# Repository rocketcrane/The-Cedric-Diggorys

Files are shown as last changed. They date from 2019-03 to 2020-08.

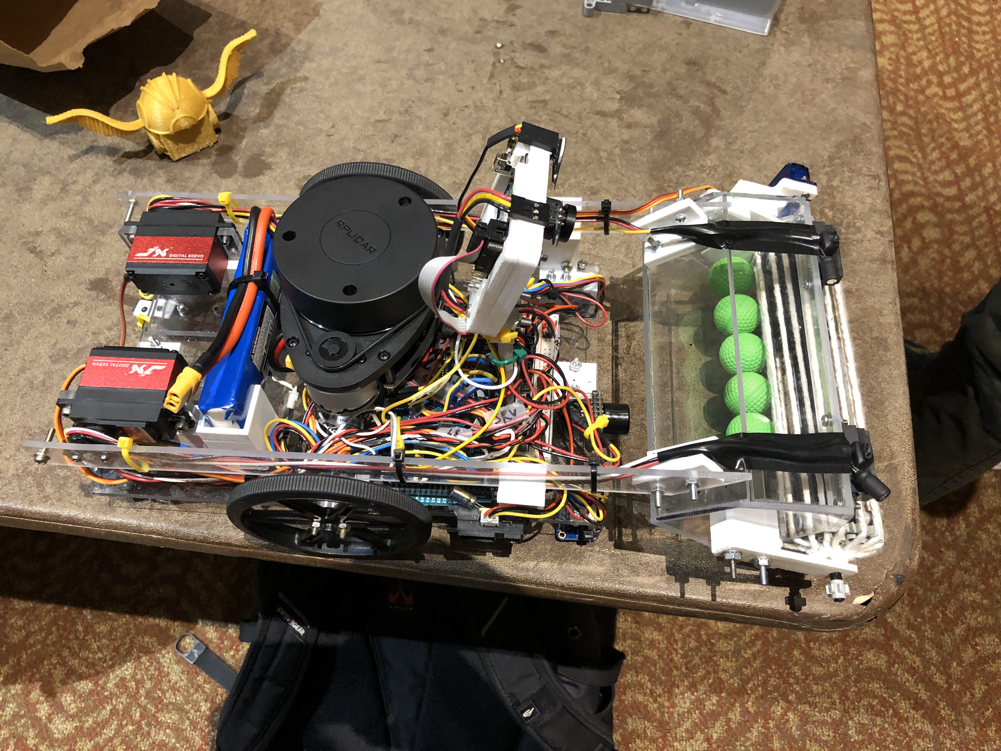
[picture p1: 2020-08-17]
cedric-pictures/IMG_1929.jpeg

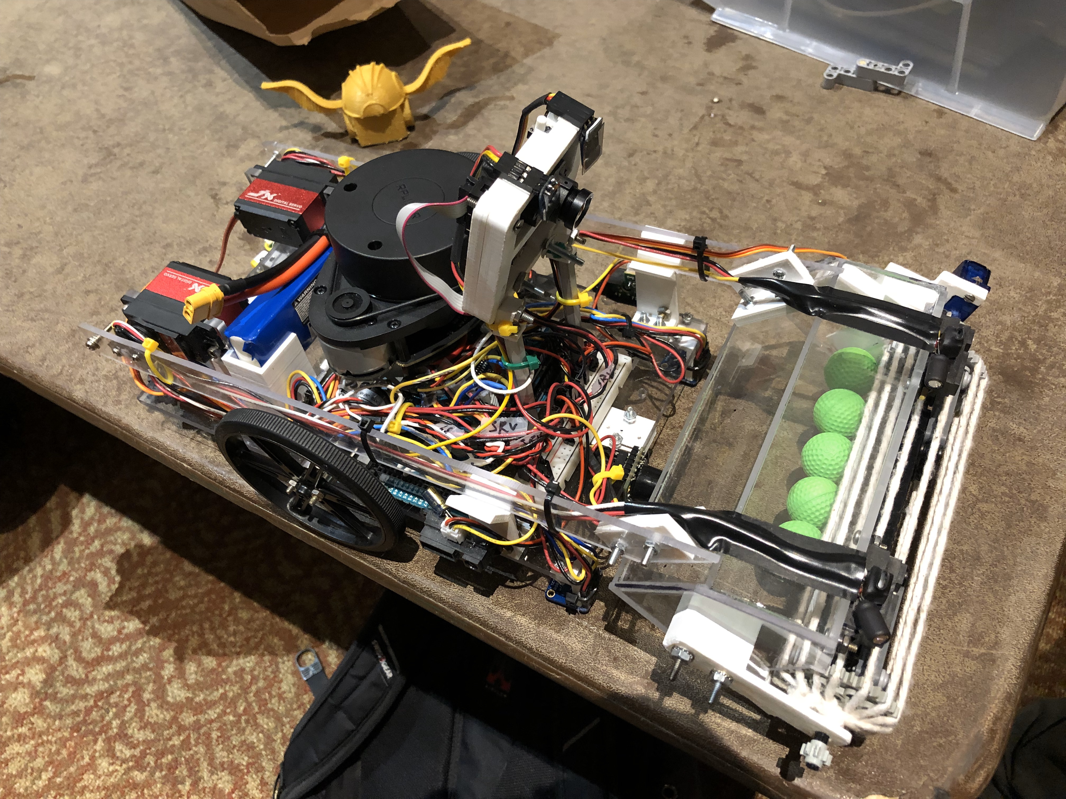
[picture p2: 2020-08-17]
cedric-pictures/IMG_1928.jpeg

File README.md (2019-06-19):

# We are the Triwizard Tournament Co-champions!
Update: We are the quidditch tournament champions!

Congratulations Cedric.

Best of luck to Ben at his new job,

Tomas with his Computer Science Major,

and Lingxiu with his Cognitive Science one.

-------------------------The Cedric Diggorys signing out.-------------------------

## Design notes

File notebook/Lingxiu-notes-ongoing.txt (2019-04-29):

# Notes for Lingxiu Zhang

First 3 weeks:
  Organized meetings, took (most of our) notes, brainstormed, found different types of sensors, hooked up sensors to Arduino
  forked TEAM-YELLOW, created the-Cedric-Diggorys

Feb 18, 2019
  Soldered pins to sonar sensor, hooked sensors and motors up to arduino, soldered wires to motor. Tested different types of motors. Discussed with other people in our group about the drivetrain, chassis, ball-pick-up and ball-shooting mechanisms. Asked Carl (with other members) about our design ideas, was told to meet him tomorrow. Did research on wiring/using Arduino motor shield.
  Also researched about mecanum/omni wheels and the possibility of using a roomba extractor brush as a part of our ball-pick-up mechanism. Turns out omni wheels can be arranged in an x-drive or a triangle-drive allowing for full mobility, including strafing to both sides. Put this in our (google doc) team notes.

Feb 22, 2019
  Discussed finishing milestones, robot's physical design etc. Worked with Ben to build a LEGO prototype robot capable of moving forward. Searched online for wheels that we could use for our robot and settled on two possible wheels types. Took notes. Researched LIDAR and a real SLAM LIDAR that might help our robot a lot. Discussed if it would be worth it to buy such a LIDAR, and we came to the conslusion that if we still had most of our budget by spring break, then we would get it. Talked about using rubber bands in our cylinder, and decided to get rubber bands and prototype our design next time.
  
Feb 24 - Apr 4, 2019
  Built an iteration of the chassis design on foam core board, did all the electronics work, designed and prototyped a quaffle-collection mechanism, built two prototypes of the mechanism (one from Legos, one from foam core board). Researched and bought a LIDAR unit during spring break. Worked with Carl to start build a proper chassis from Arcrylic.
  
Apr 4 - Apr 21
  Designed and built the third (and definitely last) iteration of the chassis + all hardware. I designed + prototyped all arcylic parts, which were built by Cart at the machine shop. All 3D-printed parts, except the camera mount, were designed and printed by myself. I  wired and installed all the electronics. I put together nearly all robot hardware, which is currently (at 4/21) 95% finished, and I plan to move on to support Ben with the software effort. What's left of the hardware work is installing the light sensors with polarized filters, and installing a few more IR sensors.
   I have been in the lab at least two extra days each week for the last three weeks working primarily on the robot hardware. Setting up and debugging the 3D printer took about three days, and I finally realized that the filament was the main culprit in causing all prints to warp badly. So I replaced the filament, and the printer didn't give me any issues after that. The next few days were spent coordinating with Carl to build the plow and servo mounts, printing and installing multiple parts including caster wheel mounts and ultrasonic sensor mounts, and wiring sensors. Then I mounted the Pixycam by modifying Tomas's 3D printed mount and mounting it to standoffs on the chassis. Then more parts were mounted, blah blah blah, dramatic music and montage of power tools and 3D printing, and the hardware side of things is almost completely finished.

Apr 21 - Apr 29
  Finished robot hardware. Wired and installed all IR sensors, a sonar sensor, and two light sensors with polarized light detection. Installed a replacement servo for the low-torque servo. Built a battery voltage monitor for the Arduino. Tweaked and optimized wiring on the robot. Designed and 3d printed battery mount brackets.
  Starting to help Ben with software.

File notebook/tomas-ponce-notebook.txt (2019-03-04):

Week 3: 2/11/19-2/17/19

This week I focused on looking up some research on the senors we have avaliable to us. In particular was researching
the limitations that the sensors each had.
	-Brighter surfaces are easier for the infrared to detect since it can't detect dark surfaces very well
	-Ultrasonics aren't as good as infrared at defining edges
The rest of the team feel very condient in being able to use the senors.
I was also researching potential drive trains for the robot. So far I really like the use of mecanum for the robot.
Beginning to model our ideas. So far have just drawn them on paper. 
Hope to have some parts of the robot made next week.

Week 4: 2/18/19-2/24/19

This week I was focused only on modeling the parts of our robot. We have made the decision to design/model the final 
parts of our robot as we construct our prototype. The parts I managed to complete were the plow and the two seperate 
models that will be used to hold our camera. The plow will go in front of our robot as it drives fowards and picks up 
balls along the way. The two parts that will hold the camera are to be printed seperately and then assemble together 
for the camera. The actual body and the base that will hold the wheels are to be made next. 

Week 5: 2/25/19-3/4/19 

This week I finally managed to get one of the parts printed. After a while of trying to get the fie to work with
one of the printers, the front part of the camera holder was made. The print was not ideal. One lesson learned from
the print was to increase the scale of the part. Due to several factors concerning the printer and how the plastic
dried, the print was just a little too tight to fit neatly around the camera. The holes that went around the part 
also did not come out as desired. The pegs that were originally a part of the design also were a problem. They were 
changed to holes so a bolt and nut could hold the two halves together. The back half of the camera was also changed 
due to this revelation. Work on the chasis model and other features are underway.

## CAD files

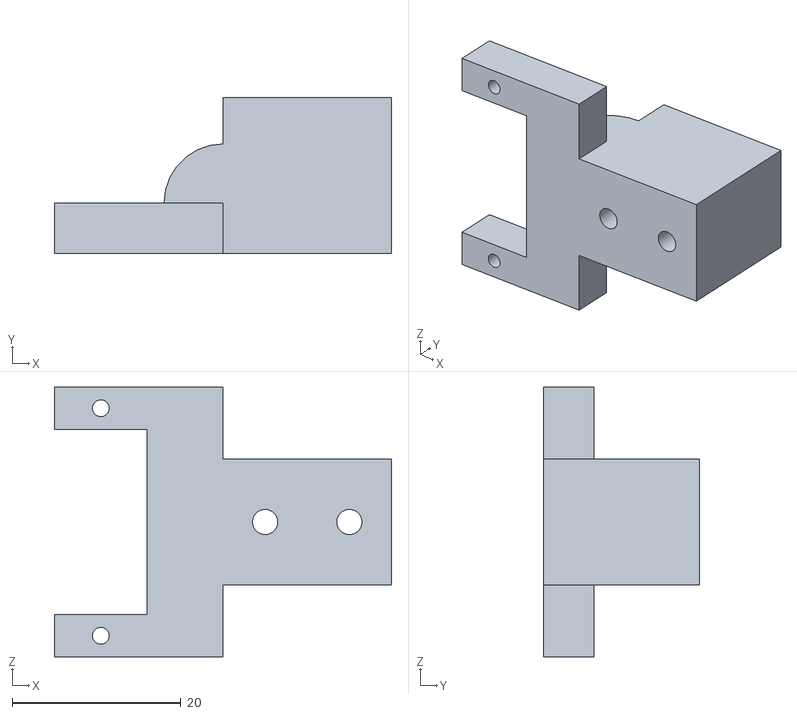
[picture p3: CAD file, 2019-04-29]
notebook/Lingxiu-3d-models/CRServo-Mt 1.1.stl
40.0 x 18.5 x 32.0

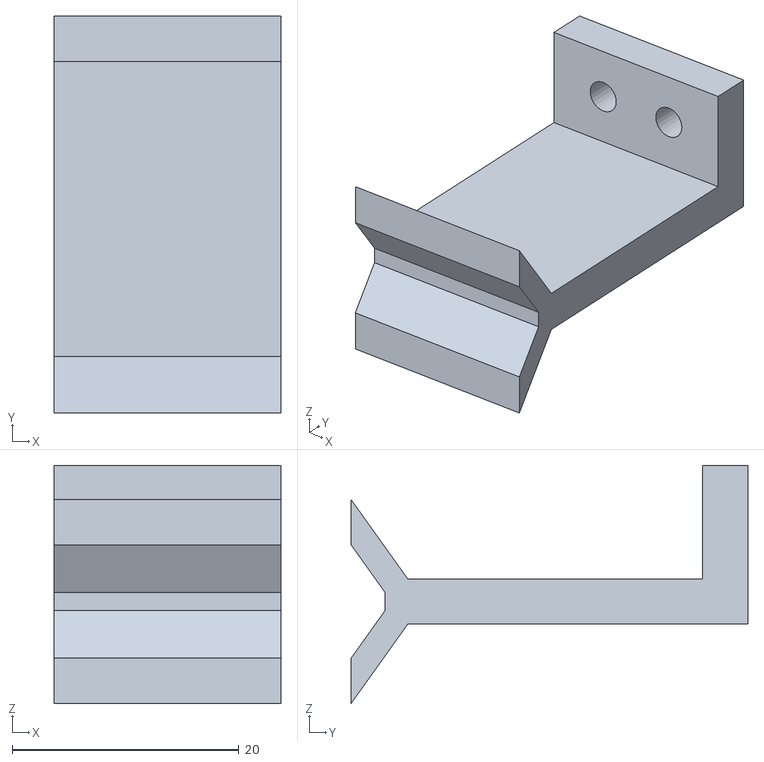
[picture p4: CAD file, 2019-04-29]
notebook/Lingxiu-3d-models/WD6_Stop-Arm 1.1.stl
20.0 x 35.0 x 21.0

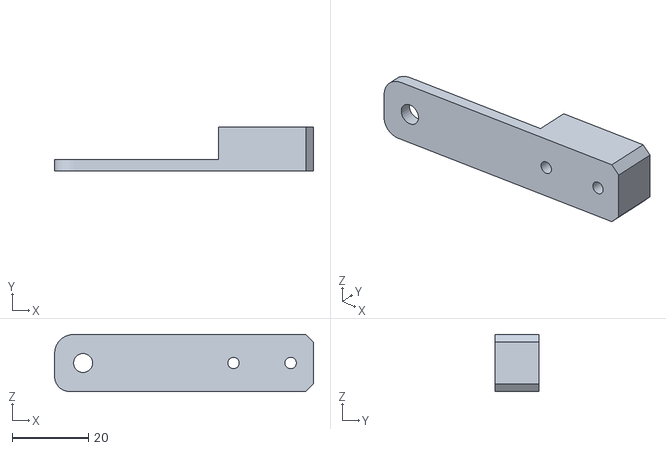
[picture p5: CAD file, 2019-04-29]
notebook/Lingxiu-3d-models/Cylinder-Mt 1.1.stl
68.0 x 11.6 x 15.0

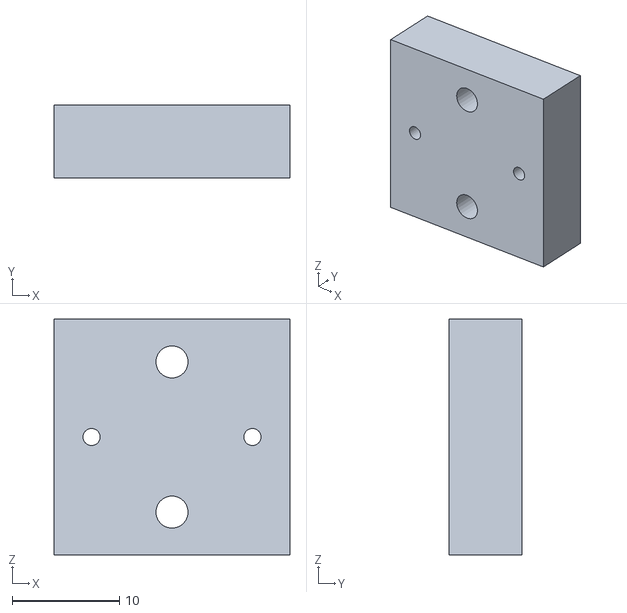
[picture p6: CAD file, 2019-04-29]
notebook/Lingxiu-3d-models/Caster-Mt 1.0.stl
22.0 x 6.80 x 22.0

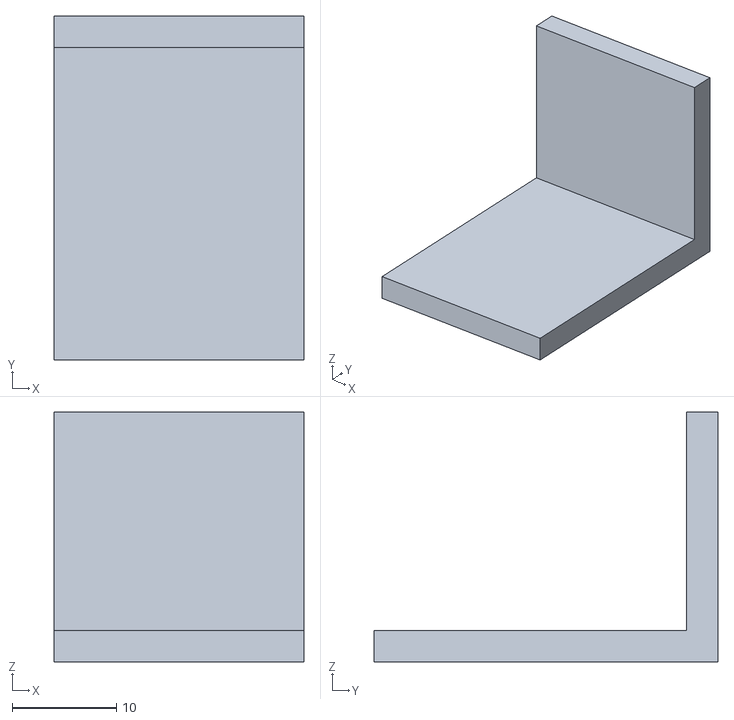
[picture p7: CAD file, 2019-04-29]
notebook/Lingxiu-3d-models/bat-mt 1.0.stl
24.0 x 33.0 x 24.0

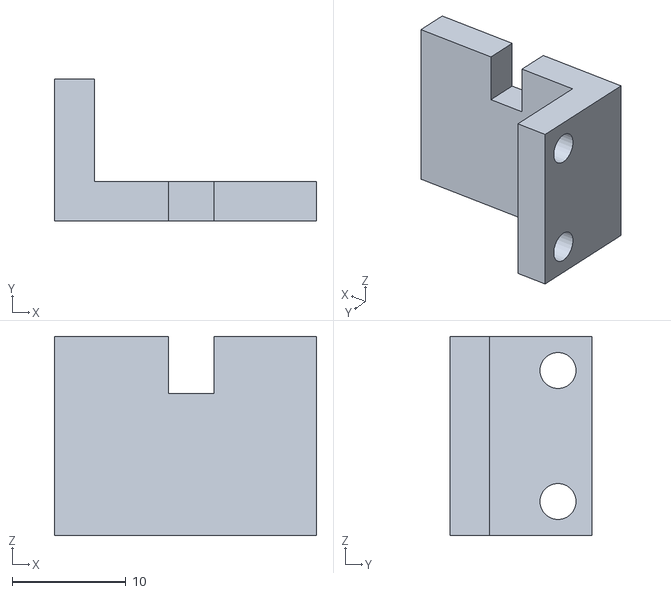
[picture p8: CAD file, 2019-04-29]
notebook/Lingxiu-3d-models/Ultson-Mt 1.0.stl
23.0 x 12.5 x 17.5

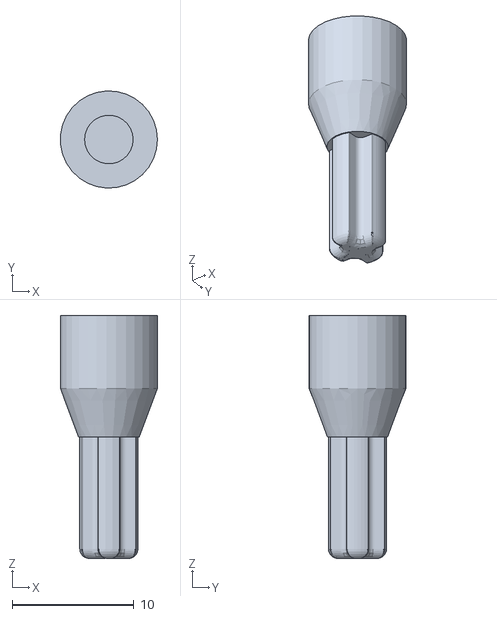
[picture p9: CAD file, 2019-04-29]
notebook/Lingxiu-3d-models/Servo-Lego Axle v2.0.stl
7.98 x 7.99 x 20.0

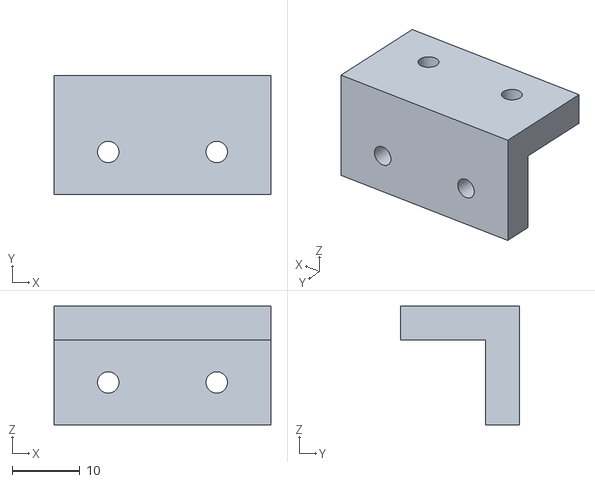
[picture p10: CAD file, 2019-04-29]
notebook/Lingxiu-3d-models/l-bracket 1.0.stl
32.0 x 17.5 x 17.5

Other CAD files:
notebook/Lingxiu-3d-models/chassis.dwg
Robot 3-D Models/90mm Wheel.ipt
Robot 3-D Models/BS #1.ipt
Robot 3-D Models/BS #2.ipt
Robot 3-D Models/BS #3.ipt
Robot 3-D Models/JX PDI 6221MG Servo.ipt
Robot 3-D Models/Mounting Hub.ipt
Robot 3-D Models/Part2.ipt
Robot 3-D Models/Plow.ipt
Robot 3-D Models/arduino mega 2560.ipt
Robot 3-D Models/arm.ipt
Robot 3-D Models/back-cam.ipt
Robot 3-D Models/ball.ipt
Robot 3-D Models/base plate.ipt
Robot 3-D Models/battery-holder-two.ipt
Robot 3-D Models/battery-holder.ipt
Robot 3-D Models/battery.ipt
Robot 3-D Models/breadboard.ipt
Robot 3-D Models/camera-brackets-angle.ipt
Robot 3-D Models/fixed-back-cam.ipt
Robot 3-D Models/fixed-front-cam.ipt
Robot 3-D Models/front-cam.ipt
Robot 3-D Models/jam-protector-two.ipt
Robot 3-D Models/jam-protector.ipt
Robot 3-D Models/motor-rail.ipt
Robot 3-D Models/motor.ipt
Robot 3-D Models/plowV2.ipt
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

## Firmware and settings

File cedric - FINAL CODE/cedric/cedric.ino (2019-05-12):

#include <Adafruit_TCS34725softi2c.h>

#include <Arduino.h>
#include <RPLidar.h>
#include <Wire.h>
#include <Servo.h>
#include <SPI.h>
#include <Pixy.h>
#include <Adafruit_TCS34725.h>
#include "sensors.h"
#include "motors.h"
#include "servos.h"
#include "variables.h"

int const STARTINGSIDE = BLUE_SIDE; //CHOOSE STARTING SIDE

void setup() {
  //WAIT FOR X SECONDS
  delay(0 * 1000L);

  //------------------------PIN MODES------------------------
  pinMode(LEFT_FRONT_IR_PIN, INPUT);
  pinMode(RIGHT_FRONT_IR_PIN, INPUT);
  pinMode(LEFT_REAR_IR_PIN, INPUT);
  pinMode(RIGHT_REAR_IR_PIN, INPUT);
  pinMode(LEFT_IR_PIN, INPUT);
  pinMode(RIGHT_IR_PIN, INPUT);
  pinMode(SONAR_PIN, INPUT);
  pinMode(LEFT_LIGHT_PIN, INPUT);
  pinMode(RIGHT_LIGHT_PIN, INPUT);
  pinMode(VOLT_PIN, INPUT);
  pinMode(A_DIRECTION_PIN, OUTPUT);
  pinMode(B_DIRECTION_PIN, OUTPUT);
  pinMode(A_BRAKE_PIN, OUTPUT);
  pinMode(B_BRAKE_PIN, OUTPUT);

  //------------------------START ROBOT------------------------
  Serial.begin(9600);
  Serial.println("-------------------CEDRIC DIGGORY-------------------");
  Serial.println("----------TRIWIZARD TOURNAMENT CO-CHAMPION----------");
  Serial.print("booting");
  for (int i = 0; i < 20; i++) {
    delay(200);
    Serial.print(".");
  }
  Serial.println();

  //START RGB SENSORS AND PIXY
  leftRGB.begin();
  rightRGB.begin();
  rearRGB.begin();
  pixy.init();

  //RESET VARIABLES
  quaffleDetectedRight = 0;
  quaffleDetectedLeft = 0;
  leakyIntegrator = 40;
  location = 0;
  currSide = 0;
  state = COLLECTING;

  //SET INITIAL STATE
  if (STARTINGSIDE == BLUE_SIDE) {
    Serial.println("BLUE side home");
    currSide = BLUE_SIDE;
    location = BLUE_SIDE;
    homeSide = BLUE_SIDE;
    goalSide = RED_SIDE;
    scoringWallSidePin = RIGHT_IR_PIN;
    scoringTurnDirection = LEFT;
  }
  if (STARTINGSIDE == RED_SIDE) {
    Serial.println("RED side home");
    currSide = RED_SIDE;
    location = RED_SIDE;
    homeSide = RED_SIDE;
    goalSide = BLUE_SIDE;
    scoringWallSidePin = RIGHT_IR_PIN;
    scoringTurnDirection = LEFT;
  }

  //START MOVING
  if (state == COLLECTING) forward(FORWARD_SPEED);
  rollIn();
}

void loop() {
  //------------------------MAIN ROBOT CODE------------------------
  while (millis() < END_TIME) {

    //UPDATE VARIABLES AND GRAB SENSOR DATA
    unsigned long currentMillis = millis();
    //grab pixy blocks
    uint16_t blocks;
    blocks = pixy.getBlocks();
    //generic loop counter for Pixy
    int j;
    quaffleSeenThisLoop = 0;
    //grab RGB sensor data & convert to HSV
    leftRGB.getRawData(&red, &green, &blue, &clear);
    RGBtoHSV(red, green, blue, &leftHue, &s, &v);
    rightRGB.getRawData(&red, &green, &blue, &clear);
    RGBtoHSV(red, green, blue, &rightHue, &s, &v);
    rearRGB.getRawData(&red, &green, &blue, &clear);
    RGBtoHSV(red, green, blue, &rearHue, &s, &v);
    //CHECK BATTERY LEVEL
    if (getVoltage() < LOW_BATTERY_LEVEL) {
      Serial.println("I'LL BE BACK");
    }

    //SWITCH TO SCORING MODE IF TIME HAS PAST
    if (currentMillis >= scoreTime && isRed(rightHue) && state == COLLECTING) {
      lastColorSeen = RED_TAPE;
      brake();
      state = FOLLOW_LINE;
      raiseArmHigher();
      Serial.println("found line");
    }

    //------------------------COLLECTING STATE------------------------
    if (state == COLLECTING) {

      //UPDATE LEAKY INTEGRATOR
      if (leakyIntegrator > DECAY && currentMillis - previousMillis >= INTERVAL) {
        leakyIntegrator -= DECAY;
        previousMillis = millis(); //updates time
        //prints integrator values
        //Serial.print("Integrator: ");
        //Serial.println(leakyIntegrator);
      }

      //IF INTEGRATOR IS HIGH, REVERSE A BIT THEN TURN UNTIL YOU SEE OPEN SPACE
      if (leakyIntegrator > SENSITIVITY) {
        //variables to tune behavior
        int turnLoopAmount = 3 * 100; //roughly time in seconds
        int turnRandomTime = 600;
        int backTime = 500;
        //sets leaky integrator back to RESET value
        leakyIntegrator = RESET;
        //prints that integrator is high
        Serial.println("Integrator HIGH");

        //reverses a bit
        reverseTime(backTime);

        //turns the opposite direction to current motor state
        if (motorState == SPINLEFT || motorState == TURNLEFT) {
          right(TURNING_SPEED);
          Serial.println("Turning RIGHT (high)");
          for (int i = 0; i < turnLoopAmount; i++ && getIRVal(LEFT_FRONT_IR_PIN) < 40 && getIRVal(RIGHT_FRONT_IR_PIN) < 40) {
            delay(10);
          }
          forward(FORWARD_SPEED);
        }
        else if (motorState == SPINRIGHT || motorState == TURNRIGHT) {
          left(TURNING_SPEED);
          Serial.println("Turning LEFT (high)");
          for (int i = 0; i < turnLoopAmount; i++ && getIRVal(LEFT_FRONT_IR_PIN) < 40 && getIRVal(RIGHT_FRONT_IR_PIN) < 40) {
            delay(10);
          }
          forward(FORWARD_SPEED);
        }
        //or do a random turn if robot is not currently turning
        else {
          Serial.println("Turning RANDOM (high)");
          randTurn(turnRandomTime);
        }
      }

      //IF INTEGRATOR DECAYS TO ZERO, BACK UP AND THEN TURN IN OPPOSITE DIRECTION TO CURRENT TURNING DIRECTION
      if (leakyIntegrator <= DECAY) {
        //variables to tune behavior
        int turnOppositeTime = 400;
        int turnRandomTime = 600;
        int backTime = 500;
        //reset leaky integrator to RESET
        leakyIntegrator = RESET;
        //prints that integrator is LOW
        Serial.println("Integrator LOW");

        //reverses a bit
        reverseTime(backTime);

        //turns opposite direction to current motor state
        if (motorState == SPINLEFT || motorState == TURNLEFT) {
          Serial.println("Turning RIGHT (low)");
          spinRightTime(turnOppositeTime);
        }
        else if (motorState == SPINRIGHT || motorState == TURNRIGHT) {
          Serial.println("Turning LEFT (low)");
          spinLeftTime(turnOppositeTime);
        }
        //or do a random turn if robot is not currently turning
        else {
          Serial.println("Turning RANDOM (low)");
          randTurn(turnRandomTime);
        }
      }

      //IF LEFT RGB SENSOR OR FRONT LEFT IR SENSOR IS TRIGGERED, BACK UP A BIT AND SPIN RIGHT
      if (isYellow(leftHue) || getIRVal(LEFT_FRONT_IR_PIN) < 6) {
        //variables to tune behavior
        unsigned long backTime = 200;
        unsigned long turnTime = 400;
        //integrate leaky integrator
        leakyIntegrator += INTEGRATE;
        Serial.println("LRGB/FLIR turning RIGHT");

        reverseTime(backTime);
        spinRightTime(turnTime);
      }

      //IF RIGHT RGB SENSOR OR FRONT RIGHT IR SENSOR IS TRIGGERED, BACK UP A BIT AND SPIN LEFT
      if (isYellow(rightHue) || getIRVal(RIGHT_FRONT_IR_PIN) < 6) {
        //variables to tune behavior
        unsigned long backTime = 200;
        unsigned long turnTime = 400;
        //integrate leaky integrator
        leakyIntegrator += INTEGRATE;
        Serial.println("RRGB/FRIR turning LEFT");

        reverseTime(backTime);
        spinLeftTime(turnTime);
      }

      //IF LEFT IR SENSOR OR RIGHT REAR IR SENSOR IS TRIGGERED, TURN RIGHT
      if (getIRVal(LEFT_IR_PIN) < 5 || getIRVal(RIGHT_REAR_IR_PIN) < 5) {
        //variables to tune behavior
        unsigned long turnTime = 500;
        //integrate leaky integrator
        leakyIntegrator += INTEGRATE;
        Serial.println("LIR/RRIR turning RIGHT");

        turnLeftTime(turnTime);
      }

      //IF RIGHT IR SENSOR OR LEFT REAR IR SENSOR IS TRIGGERED, TURN LEFT
      if (getIRVal(RIGHT_IR_PIN) < 5 || getIRVal(LEFT_REAR_IR_PIN) < 5) {
        //variables to tune behavior
        unsigned long turnTime = 500;
        //integrate leaky integrator
        leakyIntegrator += INTEGRATE;
        Serial.println("RIR/RLIR turning RIGHT");

        turnRightTime(turnTime);
      }

      //IF PIXYCAM SEES A GREEN BALL, UPDATE VARIABLES AND TRY TO FOLLOW
      if (blocks) {

        //for each block, check signature
        for (j = 0; j < blocks; j++) {
          if (pixy.blocks[j].signature == GREEN_SIG) {
            //update variables
            loopsSinceQuaffleSeen = 0;
            quaffleSeenThisLoop = 1;
            quaffleDetected = 1;
            //get quaffle X and Y
            quaffleX = pixy.blocks[j].x;
            quaffleY = pixy.blocks[j].y;
            Serial.println("quaffle DETECTED");
          }
          if (pixy.blocks[j].signature == YELLOW_SIG && (pixy.blocks[j].height * pixy.blocks[j].width) > 300) {
            //update variables
            loopsSinceGoalSeen = 0;
            goalSeenThisLoop = 1;
            goalDetected = 1;
            Serial.println("goal DETECTED");
          }
        }

        //TRY TO FOLLOW A GREEN BALL IF IT EXISTS
        if (quaffleSeenThisLoop) {
          //if quaffle is within buffer begin turning
          if (quaffleX > (155 + ALLOWABLE_BUF) && quaffleDetectedRight == 0) {
            forwardRight(TURNING_SPEED);
            Serial.println("quaffle detected to the RIGHT");
            quaffleDetectedRight = 1;
          }
          if (quaffleX < (155 - ALLOWABLE_BUF) && quaffleDetectedLeft == 0 && !quaffleDetectedRight) {
            forwardLeft(TURNING_SPEED);
            Serial.println("quaffle detected to the LEFT");
            quaffleDetectedLeft = 1;
          }
          //if quaffle is centered then go forward
          if (quaffleX < 155 + TARGET_BUF && quaffleDetectedRight == 1 ) {
            forward(FORWARD_SPEED);
            quaffleDetectedRight = 0;
            Serial.println("quaffle CENTERED");
          }
          if (quaffleX > 155 - TARGET_BUF && quaffleDetectedLeft == 1) {
            forward(FORWARD_SPEED);
            quaffleDetectedLeft = 0;
            Serial.println("quaffle CENTERED");
          }
        }
      }

      //if no quaffle has been seen this loop, increment counter
      if (!quaffleSeenThisLoop) {
        loopsSinceQuaffleSeen ++;
      }
      //if no goal has been seen this loop, increment counter
      if (!goalSeenThisLoop) {
        loopsSinceGoalSeen ++;
      }

      //if quaffle hasn't been seen in X loops, update variables
      if (loopsSinceQuaffleSeen > 10 && quaffleDetected) {
        Serial.print("quaffle DISAPPEARED");
        //update variables
        quaffleDetectedRight = 0;
        quaffleDetectedLeft = 0;
        quaffleDetected = 0;
      }
      //if goal dissapears
      if (loopsSinceGoalSeen > 10 && goalDetected) {
        Serial.print("goal DISAPPEARED");
        //update variables
        quaffleDetected = 0;
      }
    }

    //------------------------FOLLOW LINE STATE------------------------
    if (state == FOLLOW_LINE) {
      Serial.println("following line");
      Serial.println(rightHue);
      // Serial.println(rightHue);
      if (isRed(rightHue)) {
        Serial.println("red");
        forward(FORWARD_SPEED);
        lastColorSeen = RED_TAPE;
      }
      if (isBlue(rightHue) || lastColorSeen == BLUE_TAPE) {
        Serial.println("blue");
        if (homeSide == BLUE_SIDE) left(TURNING_SPEED);
        else right(TURNING_SPEED);
        lastColorSeen = BLUE_TAPE;
      }
      if (isGray(rightHue) && lastColorSeen == RED_TAPE) {
        Serial.println("gray");
        if (homeSide == BLUE_SIDE) right(TURNING_SPEED);
        else left(TURNING_SPEED);
      }
      if (isYellow(rightHue)) {
        brake();
        Serial.println("Wall detected");
        state = SCORING;
        while (!(isGray(rightHue))) {
          rightRGB.getRawData(&red, &green, &blue, &clear);
          RGBtoHSV(red, green, blue, &rightHue, &s, &v);
          forward(TURNING_SPEED);
        }
        brake();
        while (!(isYellow(rightHue))) {
          Serial.println(rightHue);
          rightRGB.getRawData(&red, &green, &blue, &clear);
          RGBtoHSV(red, green, blue, &rightHue, &s, &v);
          if (scoringTurnDirection == RIGHT) {
            right(TURNING_SPEED);
          }
          else {
            left(TURNING_SPEED);
          }
        }
        brake();
        Serial.println("done no yellow turn");
        while (isYellow(rightHue)) {
          Serial.println(rightHue);
          rightRGB.getRawData(&red, &green, &blue, &clear);
          RGBtoHSV(red, green, blue, &rightHue, &s, &v);
          if (scoringTurnDirection == RIGHT) {
            right(TURNING_SPEED);
          }
          else {
            left(TURNING_SPEED);
          }
        }
        Serial.println("done yellow turn");
        brake();
        while (isYellow(rearHue)) {
          rearRGB.getRawData(&red, &green, &blue, &clear);
          RGBtoHSV(red, green, blue, &rearHue, &s, &v);
          if (scoringTurnDirection == RIGHT) {
            left(TURNING_SPEED);
          }
          else {
            right(TURNING_SPEED);
          }
        }
        lowerArmHigher();
      }
    }

    //------------------------SCORING STATE------------------------
    if (state == SCORING) {
      float wallDist = getIRVal(scoringWallSidePin);
      Serial.println(wallDist);
      if (wallDist < 8 || isYellow(rightHue)) {
        Serial.println("too close to wall");
        if (scoringTurnDirection == RIGHT) right(TURNING_SPEED);
        else left(TURNING_SPEED);
      }

      else {
        if (scoringTurnDirection == RIGHT) forwardLeft(FORWARD_SPEED);
        else forwardRight(FORWARD_SPEED);
      }
      if (getIRVal(LEFT_FRONT_IR_PIN) < 8 && goalDetected) {
        Serial.println("found goal");
        Serial.println(wallDist);
        Serial.println(getIRVal(LEFT_FRONT_IR_PIN));
        Serial.println(getIRVal(RIGHT_FRONT_IR_PIN));
        state = COLLECTING;
        scoreTime = currentMillis + COLLECTING_TIME;
        slowLineUpWall();
        delay(1000);
        raiseArm();
        forward(FORWARD_SPEED);
        delay(400);
        brake();
        rollOut();
        delay(2000);
        reverse(FORWARD_SPEED);
        delay(500);
        brake();
        lowerArm();
        rollIn();
      }
    }
  }


  //STOP ROBOT
  brake();
  stopRoll();
  Serial.println("-------------------MISSION ACCOMPLISHED-------------------");
  Serial.println("----------------CEDRIC DIGGORY SIGNING OFF----------------");
  delay(100);
  exit(0);
}

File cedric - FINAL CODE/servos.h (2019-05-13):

#ifndef SERVOS_H
#define SERVOS_H

#include <Adafruit_TCS34725softi2c.h>

#include <Arduino.h>
#include <RPLidar.h>
#include <Wire.h>
#include <Servo.h>
#include <SPI.h>
#include <Pixy.h>
#include <Adafruit_TCS34725.h>
#include "variables.h"

//------------------------PINS------------------------
//ACTUATORS
int const LEFT_SERVO_PIN = 46;
int const RIGHT_SERVO_PIN = 45;
int const ROLLER_PIN = 10;

//------------------------CONSTANTS------------------------
//ARM CONSTANTS
int const RIGHT_START = 13;
int const LEFT_START = 160 - RIGHT_START;
int const LIFT_ANGLE = 35;
const int HIGHER_LIFT_ANGLE = 55;

//ROLLER STATE CONSTANTS
int const IN = 1;
int const OUT = 2;
int const STOP = 0;

//------------------------DECLARATIONS------------------------
Servo leftServo;
Servo rightServo;
Servo roller;

//------------------------SERVO FUNCTIONS------------------------

// ROLLIN
// ------------------------------------------
// starts roller to collect balls
void rollIn() {
  roller.attach(ROLLER_PIN);
  roller.write(0);
  //update roller state
  rollerState = IN;
}

// ROLLOUT
// ------------------------------------------
// starts roller to score
void rollOut() {
  roller.attach(ROLLER_PIN);
  roller.write(180);
  //update roller state
  rollerState = OUT;
}

// STOPROLL
// ------------------------------------------
// stops and detaches roller servo
void stopRoll() {
  roller.detach();
  //update roller state
  rollerState = STOP;
}

// RAISEARM
// ------------------------------------------
// raises arm
void raiseArm() {
  //attaches both arm servos
  leftServo.attach(LEFT_SERVO_PIN);
  rightServo.attach(RIGHT_SERVO_PIN);
  for (int pos = 0; pos <= LIFT_ANGLE; pos++) { // goes from 0 degrees to 180 degrees
    // in steps of 1 degree
    rightServo.write(RIGHT_START + pos); // tell servo to go to position in variable 'pos'
    leftServo.write(LEFT_START - pos);
    delay(15); // waits 15ms for the servo to reach the position
  }

  if (rollerState == IN) {
    stopRoll();
  }
}

// LOWERARM
// ------------------------------------------
// lowers arm
void lowerArm() {
  for (int pos = LIFT_ANGLE; pos >= 0; pos -= 1) { // goes from 180 degrees to 0 degrees
    rightServo.write(pos + RIGHT_START); // tell servo to go to position in variable 'pos'
    leftServo.write(LEFT_START - pos);
    delay(15); // waits 15ms for the servo to reach the position
  }
  //detaches both arm servos
  leftServo.detach();
  rightServo.detach();

  if (rollerState == STOP) {
    rollIn();
  }
}

// RAISEARMHIGHER
// ------------------------------------------
// raises arm higher to get over wall
void raiseArmHigher() {
  //attaches both arm servos
  leftServo.attach(LEFT_SERVO_PIN);
  rightServo.attach(RIGHT_SERVO_PIN);

  for (int pos = 0; pos <= HIGHER_LIFT_ANGLE; pos++) { // goes from 0 degrees to 180 degrees
    // in steps of 1 degree
    rightServo.write(RIGHT_START + pos); // tell servo to go to position in variable 'pos'
    leftServo.write(LEFT_START - pos);
    delay(15); // waits 15ms for the servo to reach the position
  }

  if (rollerState == IN) {
    stopRoll();
  }
}

// LOWERARMHIGHER
// ------------------------------------------
// lowers arm from higher pos
void lowerArmHigher() {

  for (int pos = HIGHER_LIFT_ANGLE; pos >= 0; pos -= 1) { // goes from 180 degrees to 0 degrees
    rightServo.write(pos + RIGHT_START); // tell servo to go to position in variable 'pos'
    leftServo.write(LEFT_START - pos);
    delay(15); // waits 15ms for the servo to reach the position
  }
  //detaches both arm servos
  leftServo.detach();
  rightServo.detach();

  if (rollerState == STOP) {
    rollIn();
  }
}

#endif

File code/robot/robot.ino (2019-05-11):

#include <Adafruit_TCS34725softi2c.h>

#include <RPLidar.h>
#include <Wire.h>
#include <Servo.h>
#include "Adafruit_TCS34725.h"
#include <SPI.h>
#include <Pixy.h>
#define redpin 3
#define greenpin 5
#define bluepin 6
#define commonAnode true
#define SDApin1 4
#define SCLpin1 5
#define SDApin2 6
#define SCLpin2 7
#define SDApin3 22
#define SCLpin3 24


//------------MOTOR SHIELD CONSTANTS------------------------
//B is right, A is left
int const A_FORWARD = HIGH;
int const B_FORWARD = LOW;
int const A_REVERSE = !A_FORWARD;
int const B_REVERSE = !B_FORWARD;
int const A_DIRECTION_PIN = 12;
int const A_BRAKE_PIN = 9;
int const A_SPEED_PIN = 3;
int const B_DIRECTION_PIN = 13;
int const B_BRAKE_PIN = 8;
int const B_SPEED_PIN = 11;
int const FULL_SPEED = 255;
int const FORWARD_SPEED = 180;
int const TURNING_SPEED = 180;
int const REVERSE_SPEED = 170;


double const END_TIME = 120000;

//-------------SERVO DECLARATIONS------------------------
Servo leftServo;
Servo rightServo;
Servo roller;
const int LEFT_SERVO_PIN = 46;
const int RIGHT_SERVO_PIN = 45;
const int ROLLER_PIN = 10;
//-------------SENSORS DECLARATIONS--------------------------------
Pixy pixy;
struct Sensor
{
  int pin;
  float value;

};
const int LEFT_LIGHT_PIN = A4;
const int RIGHT_LIGHT_PIN = A13;
const int LEFT_FRONT_IR_PIN = A7;
const int RIGHT_FRONT_IR_PIN = A15;
const int LEFT_REAR_IR_PIN = A5;
const int RIGHT_REAR_IR_PIN = A14;
const int LEFT_IR_PIN = A3;
const int RIGHT_IR_PIN = A12;
const int SONAR_PIN = A10;
const int VOLT_PIN = A11;

const int LOW_BATTERY_LEVEL = 925;



//QUAFFLE DETECTION CONSTS
int const TARGET_BUF = 30;
int const ALLOWABLE_BUF = 100;
//COLOR SIGNATURES
int const GREEN_SIG = 2;
int const YELLOW_SIG = 1;
int const LIGHT_SIG = 4;

//State variables
int quaffleDetectedRight;
int quaffleDetectedLeft;
int quaffleDetected;
int quaffleSeenThisLoop;
int quaffleX;
int quaffleY;
int loopsSinceQuaffleSeen = 1000;
int turnCounter = 0;


const int COLLECTING = 0;
const int FOLLOW_LINE = 1;
const int SCORING = 2;
int state = COLLECTING;

//location consts and vars
int location;
int currSide;
const int BLUE_SIDE = 1;
const int RED_SIDE = 2;
const int RED_TAPE = 3;
const int BLUE_TAPE = 4;
int homeSide;
int goalSide;

//int collectingMode = 1;
//int scoringMode = 0;
//int followCenterLine = 0;
//int followWall = 0;

int goalDetected = 0;
int goalX;
int goalY;
int goalSeenThisLoop = 0;
int goalCentered = 0;
int goalDetectedLeft;
int goalDetectedRight;

//integrator states
double leakyIntegrator = 40;
unsigned long previousMillis = 0;
unsigned long interval = 250;

//Integrator Constants
double const DECAY = 2;
int const INTEGRATE = 20;
int const SENSITIVITY = 50;

const unsigned long COLLECTING_TIME = 0;//20*1000L;
const unsigned long QUICK_COLLECTING_TIME = 5*1000L;
unsigned long scoreTime = COLLECTING_TIME;

//color sensors
Adafruit_TCS34725softi2c rightRGB = Adafruit_TCS34725softi2c(TCS34725_INTEGRATIONTIME_2_4MS, TCS34725_GAIN_4X, SDApin1, SCLpin1);
Adafruit_TCS34725softi2c leftRGB = Adafruit_TCS34725softi2c(TCS34725_INTEGRATIONTIME_2_4MS, TCS34725_GAIN_4X, SDApin2, SCLpin2);
Adafruit_TCS34725softi2c rearRGB = Adafruit_TCS34725softi2c(TCS34725_INTEGRATIONTIME_2_4MS, TCS34725_GAIN_4X, SDApin3, SCLpin3);


void setup() {
  delay(2000);
  pinMode(LEFT_FRONT_IR_PIN, INPUT);
  pinMode(RIGHT_FRONT_IR_PIN, INPUT);
  pinMode(LEFT_REAR_IR_PIN, INPUT);
  pinMode(RIGHT_REAR_IR_PIN, INPUT);
  pinMode(LEFT_IR_PIN, INPUT);
  pinMode(RIGHT_IR_PIN, INPUT);
  pinMode(SONAR_PIN, INPUT);
  pinMode(LEFT_LIGHT_PIN, INPUT);
  pinMode(RIGHT_LIGHT_PIN, INPUT);
  pinMode(VOLT_PIN, INPUT);
  pinMode(A_DIRECTION_PIN, OUTPUT);
  pinMode(B_DIRECTION_PIN, OUTPUT);
  pinMode(A_BRAKE_PIN, OUTPUT);
  pinMode(B_BRAKE_PIN, OUTPUT);
  Serial.begin(9600);
   Serial.println("Starting");
  leftRGB.begin();
  rightRGB.begin();
  pixy.init();

#if defined(ARDUINO_ARCH_ESP32)
  ledcAttachPin(redpin, 1);
  ledcSetup(1, 12000, 8);
  ledcAttachPin(greenpin, 2);
  ledcSetup(2, 12000, 8);
  ledcAttachPin(bluepin, 3);
  ledcSetup(3, 12000, 8);
#else
  pinMode(redpin, OUTPUT);
  pinMode(greenpin, OUTPUT);
  pinMode(bluepin, OUTPUT);
#endif
  forward(FORWARD_SPEED);
  quaffleDetectedRight = 0;
  quaffleDetectedLeft = 0;


  initializeServos();
  rollIn();
  leakyIntegrator = 40;
  location = 0;
  currSide = 0;
}

void loop() {
  uint16_t red, green, blue, clear;
  float leftHue, rightHue, s, v;



  while (millis() < END_TIME) {
    unsigned long currentMillis = millis();
    /*
        delay(200);
        float leftVal = getIrVal(LEFT_FRONT_IR_PIN);
        float rightVal = getIrVal(RIGHT_FRONT_IR_PIN);
        Serial.print(leftVal);
        Serial.print("  ");
        Serial.println(rightVal);
    */
    //Serial.println(millis());

    //switch states if time has past
    if (currentMillis >= scoreTime && leftHue < 363 && leftHue > 353 && state == COLLECTING) {
      brake();
      state = FOLLOW_LINE;
      Serial.println("found line");
    }
    
    //
    //    if (!quaffleSeenThisLoop) loopsSinceQuaffleSeen++;
    //    if (loopsSinceQuaffleSeen > 500) {
    //      stopRoll();
    //
    //    }

    if (leakyIntegrator > DECAY && currentMillis - previousMillis >= interval) {
      leakyIntegrator -= DECAY;
      previousMillis = millis(); //updates time
    }

    leftRGB.setInterrupt(false);
    rightRGB.setInterrupt(false);

    //generic loop counter
    static int i = 0;
    int j;
    quaffleSeenThisLoop = 0;
    

    //From pixy source---------------
    //pixy blocks
    uint16_t blocks;
    char buf[32];
    // grab blocks!

    blocks = pixy.getBlocks();
    //end pixy source-----------------

    
    //from HSV source ----------------
    leftRGB.getRawData(&red, &green, &blue, &clear);
    RGBtoHSV(red, green, blue, &leftHue, &s, &v);
    rightRGB.getRawData(&red, &green, &blue, &clear);
    RGBtoHSV(red, green, blue, &rightHue, &s, &v);

    if(isRed(leftHue)){
      if(location == BLUE_TAPE){
        currSide = RED_SIDE;
      }
      location = RED_TAPE;
    }
    if(isBlue(leftHue)){
      if(location == RED_TAPE){
        currSide = BLUE_SIDE;
      }
      location = BLUE_TAPE;      
    }
    if(isGray(leftHue)){
      currSide = location;
    }
    

    //end HSV source ------------------
    //Serial.println(getVoltage());
    Serial.println(state);
    if (state == COLLECTING) {
      Serial.println("in collecting if");
      if (leakyIntegrator > SENSITIVITY) {
        Serial.println("repeated sensor inputs, turning");
        rand_turn();
        leakyIntegrator = 20;
      }

      if (leftHue < 87 && leftHue > 77) {
        Serial.println("yellow detected left");
        turn_right();
        leakyIntegrator += INTEGRATE;
      }

      if (rightHue < 90 && rightHue > 80) {
        Serial.println("yellow detected right");
        turn_left();
        leakyIntegrator += INTEGRATE;
      }
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

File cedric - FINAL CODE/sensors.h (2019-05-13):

#ifndef SENSORS_H
#define SENSORS_H

#include <Adafruit_TCS34725softi2c.h>

#include <Arduino.h>
#include <RPLidar.h>
#include <Wire.h>
#include <SPI.h>
#include <Pixy.h>
#include <Adafruit_TCS34725.h>
#include "servos.h"
#include "variables.h"

//------------------------PINS------------------------
#define redpin 3
#define greenpin 5
#define bluepin 6
#define commonAnode true
#define SDApin1 4
#define SCLpin1 5
#define SDApin2 6
#define SCLpin2 7
#define SDApin3 22
#define SCLpin3 24

//SENSORS
int const LEFT_LIGHT_PIN = A4;
int const RIGHT_LIGHT_PIN = A13;
int const LEFT_FRONT_IR_PIN = A7;
int const RIGHT_FRONT_IR_PIN = A15;
int const LEFT_REAR_IR_PIN = A5;
int const RIGHT_REAR_IR_PIN = A14;
int const LEFT_IR_PIN = A3;
int const RIGHT_IR_PIN = A12;
int const SONAR_PIN = A10;
int const VOLT_PIN = A11;

//------------------------CONSTANTS------------------------
//COLOR SIGNATURES
int const GREEN_SIG = 2;
int const YELLOW_SIG = 1;
int const LIGHT_SIG = 4;

//------------------------DECLARATIONS------------------------
Pixy pixy;
Adafruit_TCS34725softi2c rightRGB = Adafruit_TCS34725softi2c(TCS34725_INTEGRATIONTIME_2_4MS, TCS34725_GAIN_4X, SDApin1, SCLpin1);
Adafruit_TCS34725softi2c leftRGB  = Adafruit_TCS34725softi2c(TCS34725_INTEGRATIONTIME_2_4MS, TCS34725_GAIN_4X, SDApin2, SCLpin2);
Adafruit_TCS34725softi2c rearRGB  = Adafruit_TCS34725softi2c(TCS34725_INTEGRATIONTIME_2_4MS, TCS34725_GAIN_4X, SDApin3, SCLpin3);

//------------------------SENSOR FUNCTIONS------------------------

// MIN
// ------------------------------------------
// Returns minimum of three values
float MIN(float a, float b, float c) {
  float currMin = a;
  if (b < currMin) currMin = b;
  if (c < currMin) currMin = c;
  return currMin;
}

// MAX
// ------------------------------------------
// Returns maximum of three values
float MAX(float a, float b, float c) {
  float currMax = a;
  if (b > currMax) currMax = b;
  if (c > currMax) currMax = c;
  return currMax;
}

// RGBTOHSV
// ------------------------------------------
// Converts RGB values to HSV values
// h = [0,360], s = [0,1], v = [0,1]
// if s == 0, then h = -1 (undefined)
void RGBtoHSV( float r, float g, float b, float *h, float *s, float *v )
{
  r = r / 255;
  g = g / 255;
  b = b / 255;
  float min, max, delta;

  min = MIN( r, g, b );
  max = MAX( r, g, b );
  *v = max;       // v

  delta = max - min;

  if ( max != 0 )
    *s = delta / max;   // s
  else {
    // r = g = b = 0    // s = 0, v is undefined
    *s = 0;
    *h = -1;
    return;
  }

  if ( r == max )
    *h = ( g - b ) / delta;   // between yellow & magenta
  else if ( g == max )
    *h = 2 + ( b - r ) / delta; // between cyan & yellow
  else
    *h = 4 + ( r - g ) / delta; // between magenta & cyan

  *h *= 60;       // degrees
  if ( *h < 0 )
    *h += 360;
}

//------------------------SENSOR CHECK FUNCTIONS------------------------

// ISRED?
// ------------------------------------------
// returns #t if RGB sensor sees red
bool isRed(float hue) {
  return hue < 363 && hue > 345;
}

// ISBLUE?
// ------------------------------------------
// returns #t if RGB sensor sees blue
bool isBlue(float hue) {
  return hue < 208 && hue > 192;
}

// ISYELLOW?
// ------------------------------------------
// returns #t if RGB sensor sees yellow
bool isYellow(float hue) {
  return hue < 95 && hue > 77;
}

// ISGRAY?
// ------------------------------------------
// returns #t if RGB sensor sees gray
bool isGray(float hue) {
  return !isYellow(hue) && !isRed(hue) && !isBlue(hue);
}

// GETIRVAL
// ------------------------------------------
// returns IR value of sensor at PIN
float getIRVal(int pin) {
  //return sensor.value * sensor.modifier;
  // return 37-sensor.value;
  return 13 * pow(analogRead(pin) * 0.0048828125, -1);
}

// GETSONARVAL
// ------------------------------------------
// returns sonar value of sensor at PIN
float getSonarVal(int pin) {
  return analogRead(pin) / 5;
}

// GETLIGHTVAL
// ------------------------------------------
// returns light value of sensor at PIN
float getLightVal(int pin) {
  return pow(10, analogRead(pin) * 5.0 / 1024);
}

// GETVOLTAGE
// ------------------------------------------
// returns analog value of battery at PIN
float getVoltage() {
  return analogRead(VOLT_PIN);
}

#endif

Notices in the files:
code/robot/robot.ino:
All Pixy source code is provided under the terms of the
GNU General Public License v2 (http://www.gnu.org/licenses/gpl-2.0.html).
